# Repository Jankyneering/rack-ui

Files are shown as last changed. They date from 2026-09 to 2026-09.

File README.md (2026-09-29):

# Rack UI

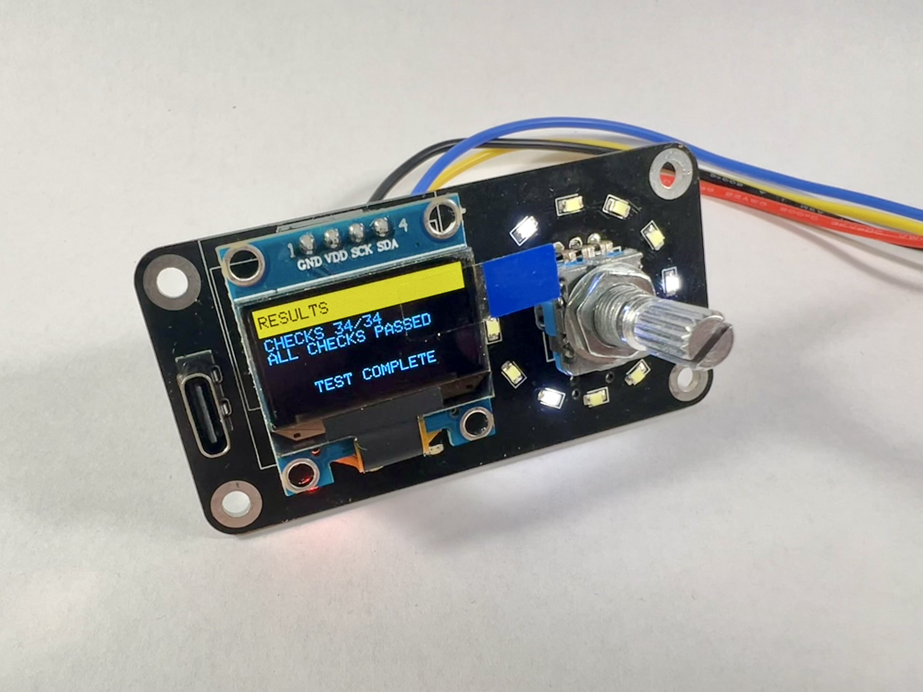
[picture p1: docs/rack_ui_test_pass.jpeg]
Rack UI - Test results

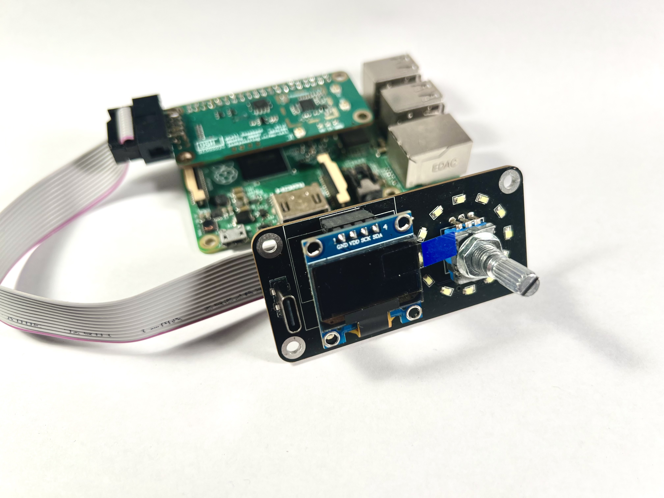
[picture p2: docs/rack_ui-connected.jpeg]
Rack UI - connected


## Contents

- [**Firmware**](firmware/src/README.md) - firmware for the Rack UI front panel controller board:
  a Puya PY32F002Ax5 (Arm Cortex-M0+) acting as an I2C peripheral, exposing a rotary encoder,
  a push button and a charlieplexed LED array to a host over a single I2C bus. Includes the
  register map, build and flashing instructions, and prebuilt release binaries.

## Flash the firmware

The Rack UI modules you can buy from the [Fred Corp. Store](https://store.fredcorp.cc) come pre-flashed with the latest firmware.

If you made your own Rack Ui board, or if you have an existing Rack Ui board that needs to be updated, you can flash the firmware using the prebuilt release binary from the [firmware release page](https://github.com/yourusername/rack-ui/releases).

### Tools

- SWD programmer (e.g. FlipperZero with DAPLink application, J-Link, etc.) compatible with the [PyOCD](https://pyocd.io/docs/debug_probes.html) toolchain.
- a [TC2030-NL](https://www.tag-connect.com/product/tc2030-idc-nl) programming probe or equivalent to connect the programmer to the Rack UI board's SWD header.

### Software dependencies

- [PyOCD](https://pyocd.io) with the [PY32F002Ax5 CMSIS pack](https://www.keil.arm.com/devices/puya-py32f002ax5/processors/) :

  ```zsh
  pip install pyocd
  pyocd pack install py32f002ax5
  ```

### Load the firmware

Use the following command to flash the firmware onto the Rack UI board. Replace `<version>` with the actual version number of the firmware you want to flash.

```zsh
pyocd load mu-cell_rack-ui_<version>.bin -t py32f002ax5
```

## Pinout

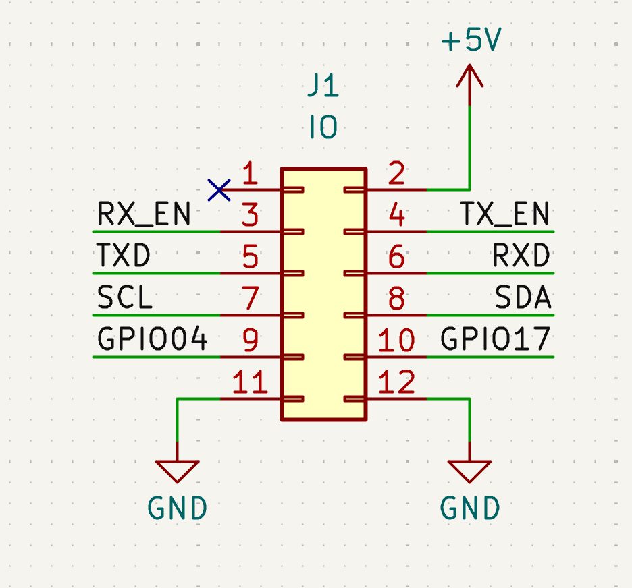
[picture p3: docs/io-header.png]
J5 expansion connector schematic


| Pin | Signal |
|---|---|
| 1 | NC |
| 2 | +5V in |
| 3 | RX_EN LED (green) |
| 4 | TX_EN LED (amber) |
| 5 | Target TXD / HT42B534-2 IC RXD |
| 6 | Target RXD / HT42B534-2 IC TXD |
| 7 | SCL |
| 8 | SDA |
| 9 | NC |
| 10 | NC |
| 11 | GND |
| 12 | GND |

---

## License & Acknowledgements

- PY32 Template from [IOsetting](https://github.com/IOsetting/py32f0-template)

Made with ❤️, lots of ☕️, and lack of 🛌  
Published under CreativeCommons BY-SA 4.0

  
This work is licensed under a [Creative Commons Attribution-ShareAlike 4.0 International License](http://creativecommons.org/licenses/by-sa/4.0/).

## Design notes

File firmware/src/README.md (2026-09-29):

# Rack UI Firmware

Firmware for the [Rack UI](../README.md) front panel controller board: a Puya **PY32F002Ax5**
(Arm Cortex-M0+) that acts as an **I2C peripheral**, exposing a rotary encoder, a push button and
a charlieplexed LED array to a host over a single I2C bus.

The firmware is built on the [py32f0-template](https://github.com/IOsetting/py32f0-template)
project using the Puya LL (Low Layer) driver library.

## What the firmware does

* **Encoder-to-I2C converter** - rotary encoder position and button presses are captured by
  interrupt and exposed through an I2C register map (see below), so a host (e.g. a Raspberry
  Pi or another MCU) can poll the panel without GPIO wiring.
* **Watchdog** - an independent watchdog (IWDG, clocked from the LSI so it keeps running
  even if the system clock fails) is enabled at boot and kicked by the main loop; if the
  firmware hangs, the MCU resets itself instead of freezing the panel. The cause of the
  last reset is exposed in register `0x02`.
* **LED driving** - 12 LEDs are driven from 4 GPIO pins by charlieplexing, with 64-step
  software PWM and optional gamma correction (curve exponent 2.2, built into a lookup table
  at boot; toggle via config bit 5). Per-LED brightness is set through registers `0x10`-`0x1B`.
  Built-in animations (loading, flashing, pulsing, breathing, ...) can drive the array
  automatically; select one through register `0x0E` and adjust its setting (speed or
  brightness) through register `0x0F`, or set it to IDLE to control the LEDs manually.
  The multiplex/PWM refresh is advanced by a TIM16 update interrupt every 24 µs, giving a
  ~54 Hz full-array refresh that is flicker-free. The main loop sleeps in `__WFI()` between
  interrupts and applies register writes between them, so I2C transactions are never blocked
  by display updates.

## Hardware / pin map

| Function | Pin | Notes |
| --- | --- | --- |
| I2C SDA | PA2 | AF12, open-drain, pull-up, 100 kHz |
| I2C SCL | PA3 | AF12, open-drain, pull-up, 100 kHz |
| Encoder A | PA5 | EXTI edge(s) per `ENCODER_TRIGGER_TOGGLE`, triggers count update (1 ms glitch guard; lines are RC-debounced by 100 nF caps) |
| Encoder B | PA4 | Input, sampled to determine rotation direction |
| Encoder switch | PA0 | EXTI both edges, debounced press counter (50 ms) |
| LED charlieplex X0 | PA6 | 12 LEDs across 4 pins |
| LED charlieplex X1 | PA7 | |
| LED charlieplex X2 | PA12 | |
| LED charlieplex X3 | PA8 | |
| Onboard LED | PB5 | Push-pull output, **active low** |

The system clock runs from the internal 8 MHz HSI. Interrupt priorities are
I2C (0) > EXTI (1) > TIM16 refresh (2), so host communication and encoder input are never
starved by the display refresh.

## I2C interface

* **Address**: `0x36` (7-bit)
* **Speed**: 100 kHz
* **Protocol**: standard register-pointer style. To read or write, first send the register
  address in a write transaction, then read or write data in the same or a following
  transaction. The register pointer auto-increments for multi-byte transfers.

### Register map

| Register | Access | Default | Description |
| --- | --- | --- | --- |
| `0x00`-`0x01` | R/W(see note) | `0x01 0x00` | **Read**: firmware version, 16-bit big-endian (BCD-friendly: v1.0 reads `0x0100`; set through `FW_VERSION_MAJOR`/`FW_VERSION_MINOR` in the Makefile). **Write**: writing any non-zero value to `0x00` issues a soft reset (the version register is not writable; a zero write is ignored). |
| `0x02` | R/O | see below | Reset cause of the most recent reset, as bit flags (see below). Latched at boot from `RCC_CSR`, then cleared there. |
| `0x03` | R/W | `0x00` | Configuration bits, see below. |
| `0x04`-`0x05` | R/W | `0x00 0x00` | Encoder rotation count, 16-bit big-endian **signed**. Incremented/decremented on rotation; cleared after the low byte is read if config bit 0 is set. |
| `0x06` | R/W | `0x00` | Encoder push button count, 8-bit unsigned. Updated on each debounced press; cleared after it is read if config bit 1 is set. |
| `0x07` | R/O | `0x00` | Encoder push button state: `0x01` while pressed (or `0x00` while pressed if config bit 4 is set). Sampled live when this register is transmitted. |
| `0x08`-`0x0D` | R/O | `0x00` | Reserved for future encoder settings. Reads return `0x00`; writes are ignored. |
| `0x0E` | R/W | `0x80` | Active animation, see [below](#animation-register-0x0e). |
| `0x0F` | R/W | `0x00` | Setting of the animation selected through `0x0E`, see [below](#animation-settings-register-0x0f). Writing a new animation id to `0x0E` reloads this register with that animation's default. |
| `0x10`-`0x1B` | R/W | `0x00` | LED brightness, one register per LED (LED 0 = `0x10` ... LED 11 = `0x1B`). `0x00` = off, `0x40` = full on; values above `0x40` clamp to full on. In IDLE mode (`0x0E` = `0x00`) these registers drive the LEDs directly; while an animation is running, the animation overwrites them. |
| `0x1C`-`0x1F` | R/O | `0x00` | Reserved. Reads return `0x00`; writes are ignored. |
| `0x20`-`0xFF` | R/W | `0x00` | General-purpose I2C RAM. Not used by the firmware; usable as 224 bytes of host scratch space. |

### Config register (`0x03`)

| Bit | Default | Description |
| --- | --- | --- |
| 0 | `0` | `1` = clear the rotation count (`0x04`-`0x05`) to zero after the low byte (`0x05`) is read. `0` (default) = keep the count. |
| 1 | `0` | `1` = clear the push count (`0x06`) to zero after it is read. `0` (default) = keep the count. |
| 2 | `0` | `1` = flip encoder increment direction. |
| 3 | `0` | `1` = decrement push count on press (saturates at 0, e.g. for "count down remaining presses" logic), `0` = increment (wraps past 255). |
| 4 | `0` | `1` = invert the reported push button state: unpressed reads `1`, pressed reads `0`. |
| 5 | `0` | `0` = gamma-correct LED brightness (default), `1` = linear brightness. |
| 6-7 | `0` | Reserved, always read 0. |

Notes:

* Writes to read-only registers are ignored (the register pointer still advances, so
  multi-byte writes can skip over them).
* A soft reset completes the current I2C transaction first, then resets the MCU; the bus
  release means the master sees a normal STOP rather than a stuck line. After reset, all
  registers return to their power-on defaults.
* The rotation counter is big-endian; read `0x04` then `0x05` in one transaction for a
  coherent value.
* Register defaults are reinitialised only at power-on/reset; the general-purpose RAM is not
  preserved across resets.

### Reset cause register (`0x02`)

Reports why the MCU last reset, latched from `RCC_CSR` at boot (then cleared
there, so the register shows the most recent reset rather than everything
accumulated since power-on). Multiple bits can be set when several causes
contributed.

| Bit | Name | Reset type |
| --- | --- | --- |
| 0 | `POR` | Power-on / brown-out (BOR/POR/PDR) reset |
| 1 | `PIN` | NRST pin reset |
| 2 | `SOFT` | Software reset (a non-zero write to register `0x00`) |
| 3 | `IWDG` | Independent watchdog timeout |
| 4 | `WWDG` | Window watchdog reset |
| 5 | `OBL` | Option byte loader reset |

A watchdog recovery therefore reads back with bit 3 (and typically bit 1) set.

### Watchdog

The independent watchdog (IWDG) is enabled once at boot with a timeout of
`IWDG_TIMEOUT_MS` (default 500 ms) and kicked by the main loop, which wakes at
least once per animation tick. It runs from the ~32 kHz LSI, independent of the
system clock, so it also recovers from a loss of the HSI. Once enabled it can
only be stopped by a reset; the soft-reset command (register `0x00`) restarts
it cleanly. While the core is halted under a debugger the watchdog is frozen
(`DBGMCU` IWDG stop), so breakpoints do not trip a reset.

### Animation register (`0x0E`)

Selects the LED animation. New animations are added by extending the table in
`User/animations.c` (see `User/animations.h` for the ID enum); unknown values fall
back to `IDLE`.

| Value | Name | Description |
| --- | --- | --- |
| `0x00` | `IDLE` | Custom control: the LEDs are driven manually via registers `0x10`-`0x1B`. |
| `0x01` | `LOADING` | Rotating loading pattern, one LED at a time reaching full brightness. |
| `0x02` | `FLASHING` | All LEDs flash on and off. |
| `0x03` | `PULSING` | All LEDs smoothly ramp up and down in brightness. |
| `0x04` | `BREATHING` | All LEDs smoothly fade in, hold, fade out and pause. |
| `0x80` | `FOLLOWING` | Every 4th LED is lit and the pattern follows the encoder rotation (configurable with the `ANIMATION_FOLLOWING_LED_STEPS` constant). |
| `0x81` | `POINT` | One LED follows the encoder rotation. |
| `0x82` | `GAUGE` | The LEDs form a bar graph, with the number of lit LEDs proportional to the encoder rotation count. The count is scaled against the maximum value set through `0x0F` (default 100) and capped between 0 and that maximum. The LEDs outside the gauge arc are held at a low brightness when `ANIMATION_GAUGE_DIM_UNUSED_LEDS` is defined (default), otherwise they keep their previous state. |
| `0x83` | `GAUGE_CENTER` | Centered version of the gauge: the middle LED of the arc is always lit, and the arc fills outward from it in one direction for positive encoder counts and the other for negative ones. The count is scaled against the positive/negative limit set through `0x0F` (default 50) and clamped symmetrically to `-limit..+limit`; the clamped value is written back to the count registers. The LEDs outside the gauge arc are dimmed like `GAUGE`. |
| `0xFE` | `ALL_ON` | All LEDs on at the brightness set through `0x0F`. Default to `CHARLIE_PWM_STEPS - 1`. |
| `0xFF` | `ALL_OFF` | All LEDs off. |

### Animation settings register (`0x0F`)

Holds the setting of the animation selected through register `0x0E` (timing
for LOADING/FLASHING/PULSING, brightness for ALL_ON, the off-state brightness
of the non-lit LEDs for FOLLOWING/POINT, the maximum value for GAUGE and the
positive/negative limit for GAUGE_CENTER).
Writing a new animation id to `0x0E` loads that animation's default into
`0x0F`; a subsequent write to `0x0F` adjusts the setting while the animation
keeps running. A value of `0` is ignored and keeps the current setting.

| Animation | Scale | Default | Meaning |
| --- | --- | --- | --- |
| `IDLE` | - | `0x00` | No setting. |
| `LOADING` | x10 ms | `10` (100 ms) | Time between LED steps of the loading pattern. |
| `FLASHING` | x10 ms | `25` (250 ms) | Time between LED state toggles. |
| `PULSING` | x1 ms | `10` (10 ms) | Time between LED brightness changes. |
| `BREATHING` | - | `0x00` | Timing fixed by the `ANIMATION_BREATHING_*` constants; no runtime setting. |
| `FOLLOWING` | x brightness | `0` (off) | Brightness of the LEDs that are not lit. |
| `POINT` | x brightness | `0` (off) | Brightness of the LEDs that are not lit. |
| `GAUGE` | x gauge max | `100` | Maximum value of the gauge range (e.g. `10` for 0-10, `250` for 0-250); the encoder count is capped between 0 and this value. |
| `GAUGE_CENTER` | x gauge limit | `50` | Positive/negative limit of the centered gauge (e.g. `10` for -10 to +10, `250` for -250 to +250); the encoder count is clamped symmetrically to `-limit..+limit` and each half of the arc covers `0..limit`. |
| `ALL_ON` | x brightness | `63` (full on) | Brightness of all LEDs. |
| `ALL_OFF` | - | `0x00` | No setting. |

Animations write their brightness values to the LED registers (`0x10`-`0x1B`) and
mark them dirty, so the main loop applies them exactly like host writes. The
animation engine ticks every 11 ms from the main loop.

### Examples (Linux `i2c-tools`)

```bash
# Read the firmware version (expects 0x00 0x01)
i2ctransfer -y 1 w1@0x36 0x00 r2

# Read the 16-bit encoder rotation count
i2ctransfer -y 1 w1@0x36 0x04 r2

# Read the button state and push count
i2cget -y 1 0x36 0x07
i2cget -y 1 0x36 0x06
# Read the reset cause of the last boot (bit flags, see the register table)
i2cget -y 1 0x36 0x02

# Enable reset-on-read for the rotation count and push count
i2cset -y 1 0x36 0x03 0x03

# Soft-reset the device (registers return to power-on defaults)
i2cset -y 1 0x36 0x00 0x01

# Set LED 0 to quarter brightness and LED 11 to full, gamma-corrected
i2cset -y 1 0x36 0x10 0x10
i2cset -y 1 0x36 0x1B 0x40

# Set all 12 LED brightness registers in one transaction
i2ctransfer -y 1 w13@0x36 0x10 0x40 0x40 0x40 0x40 0x40 0x40 0x40 0x40 0x40 0x40 0x40 0x40

# Flip encoder direction and switch LEDs to linear brightness
i2cset -y 1 0x36 0x03 0x24

# Switch to manual LED control (IDLE), then set LED 0 to quarter brightness
i2cset -y 1 0x36 0x0E 0x00
i2cset -y 1 0x36 0x10 0x10

# Switch to the pulsing animation; its default 10 ms pulse delay is loaded
# into register 0x0F
i2cset -y 1 0x36 0x0E 0x03

# Speed the pulsing animation up to a 5 ms delay
i2cset -y 1 0x36 0x0F 0x05

# Switch to the loading animation (100 ms default step time), then slow the
# rotation to 500 ms per step
i2cset -y 1 0x36 0x0E 0x01
i2cset -y 1 0x36 0x0F 0x32

# Turn all LEDs on at the default full brightness, then dim them to half
i2cset -y 1 0x36 0x0E 0xFE
i2cset -y 1 0x36 0x0F 0x20

# Switch to the gauge animation (maximum 100 is loaded into 0x0F), then
# change the range to 0-10 so each encoder detent fills a tenth of the arc
i2cset -y 1 0x36 0x0E 0x82
i2cset -y 1 0x36 0x0F 0x0A
# Switch to the centered gauge animation (limit 50 is loaded into 0x0F, so the
# count is clamped to -50..+50), then change the limit to 10 for -10 to +10
i2cset -y 1 0x36 0x0E 0x83
i2cset -y 1 0x36 0x0F 0x0A

# Turn all LEDs off
i2cset -y 1 0x36 0x0E 0xFF

# Use register 0x20 as scratch RAM
i2cset -y 1 0x36 0x20 0xA5
i2cget -y 1 0x36 0x20
```

## Building

### 1. Install the GNU Arm Embedded toolchain

Download the toolchain from
[Arm GNU Toolchain Downloads](https://developer.arm.com/downloads/-/arm-gnu-toolchain-downloads)
for your architecture and extract it, or install a distribution package:

```bash
# Debian/Ubuntu
sudo apt-get install gcc-arm-none-eabi libnewlib-arm-none-eabi
# -> toolchain in /usr/bin, set ARM_TOOLCHAIN=/usr/bin when building
```

### 2. Build

From the `firmware/src` directory:

```bash
make ARM_TOOLCHAIN=/usr/bin        # or point ARM_TOOLCHAIN at your toolchain's bin/ directory
```

Useful variants:

```bash
make clean                        # remove build products
V=1 make                          # verbose output (prints full command lines)
make echo-version                 # print the firmware version (MAJOR.MINOR)
```

The firmware version is defined in the Makefile through `FW_VERSION_MAJOR` /
`FW_VERSION_MINOR` (default 1.0); it is baked into registers `0x00`-`0x01` and
names the build products. Override it for a local build with:

```bash
make ARM_TOOLCHAIN=/usr/bin FW_VERSION_MAJOR=2 FW_VERSION_MINOR=3
```

#### Build flags and tunable constants

Optional `#define` flags live in the header that owns them: toggle them there
(or pass them on the compiler command line through `LIB_FLAGS` in the
Makefile) and rebuild.

Encoder flags in `User/main.h`:

* `ENCODER_TRIGGER_TOGGLE` (undefined by default) - define it to count both EncA
  edges (one tick per detent on encoders that produce one edge per detent); leave it
  commented out to count the falling edge only
* `ENCODER_DIRECTION_FLIP` (undefined by default) - define it to make clockwise
  rotation decrement the count instead of incrementing, for encoder models with
  reversed phase wiring; composes with the runtime `CFG_ENC_DIR_FLIP` config bit
* `ENCODER_AB_SWAP` (defined) - swap the phase inputs
  (EncA moves to PA4, EncB to PA5) for encoder models whose trigger output sits on
  the other phase or whose A/B pins are wired the other way round; note that
  swapping the phases also inverts the decoded direction, so combine it with
  `ENCODER_DIRECTION_FLIP` to keep the increment direction

Animation flags in `User/animations.h`:

* `ANIMATION_GAUGE_DIM_UNUSED_LEDS` (defined) - while the GAUGE or
  GAUGE_CENTER animation is active, hold the three LEDs outside the gauge arc
  at a low fixed brightness (`ANIMATION_GAUGE_UNUSED_BRIGHTNESS`) instead of
  leaving them at whatever state the previous animation or host writes left
  them in; comment it out to keep the previous state

Tunable constants (same headers, adjust and rebuild; defaults in parentheses):

* `ANIMATION_DEFAULT` (`ANIMATION_FOLLOWING`) - animation selected at power-on
  and after a soft reset
* `ANIMATION_GAUGE_SETTINGS_DEFAULT` (`100`) - gauge maximum loaded into `0x0F`
  when GAUGE is selected through `0x0E`
* `ANIMATION_GAUGE_CENTER_SETTINGS_DEFAULT` (`50`) - positive/negative gauge
  limit loaded into `0x0F` when GAUGE_CENTER is selected through `0x0E`
* `ANIMATION_GAUGE_START_LED` / `ANIMATION_GAUGE_LED_COUNT` (`8` / `9`) - first
  LED and number of LEDs forming the gauge arc; the remaining LEDs are the
  "unused" ones covered by `ANIMATION_GAUGE_DIM_UNUSED_LEDS`
* `ANIMATION_GAUGE_UNUSED_BRIGHTNESS` (`8`) - brightness of the non-gauge LEDs
  while the dim flag is in effect (`0`-`CHARLIE_PWM_STEPS - 1`)
* `ANIMATION_FOLLOWING_LED_STEPS` (`4`) - every Nth LED is lit in FOLLOWING
* `ANIMATION_BREATHING_IN_MS` / `ANIMATION_BREATHING_HOLD_MS` /
  `ANIMATION_BREATHING_OUT_MS` / `ANIMATION_BREATHING_PAUSE_MS`
  (`1500` / `750` / `2500` / `2000`) - phase durations of the breathing animation
* `ANIMATION_*_SETTINGS_DEFAULT` - defaults loaded into `0x0F` when the
  matching animation is selected (step time for LOADING/FLASHING/PULSING,
  brightness for ALL_ON, off-state brightness for FOLLOWING/POINT, gauge maximum
  for GAUGE, positive/negative limit for GAUGE_CENTER)
* `ANIMATION_LOADING_SETTINGS_MS` / `ANIMATION_FLASHING_SETTINGS_MS` (`10`) and
  `ANIMATION_PULSING_SETTINGS_MS` (`1`) - milliseconds per `0x0F` register step
* `ANIMATION_TICK_MS` (`11`) - animation engine tick, driven from the main loop
* `CHARLIE_GAMMA` (`2.2`, in `User/charlieplex.h`) - gamma exponent of the LED
  brightness curve (2.0 = simple square law, 2.2 ≈ perceptual/sRGB-style curve)
* `I2C_SLAVE_ADDR` (`0x36`, in `User/main.h`) - I2C bus address of the device
* `IWDG_TIMEOUT_MS` (`500`, in `User/main.h`) - independent watchdog timeout in
  milliseconds; the main loop must wake at least once per period or the MCU resets

Toolchain-level defines, set through the Makefile rather than a header:

* `FW_VERSION` - firmware version baked into registers `0x00`-`0x01`, derived
  from `FW_VERSION_MAJOR`/`FW_VERSION_MINOR`
* `USE_FULL_ASSERT` (undefined by default) - enable the LL drivers' parameter
  checking: `assert_param` reports the source file and line when a driver is
  called with an invalid parameter; costs some code size

Output files land in `firmware/src/Build/`, named after the app and version
(`mu-cell_rack-ui_vMAJOR.MINOR`):

| File | Description |
| --- | --- |
| `mu-cell_rack-ui_vX.Y.bin` | Raw binary image, for flashing |
| `mu-cell_rack-ui_vX.Y.hex` | Intel HEX image |
| `mu-cell_rack-ui_vX.Y.elf` | ELF with debug symbols |
| `mu-cell_rack-ui_vX.Y.lst` | Disassembly listing |

### 3. Flash

The Makefile supports flashing via **PyOCD** (DAPLink or J-Link probes) or **J-Link**,
selected with `FLASH_PROGRM`:

```bash
make ARM_TOOLCHAIN=/usr/bin flash          # uses pyocd (default)
make ARM_TOOLCHAIN=/usr/bin FLASH_PROGRM=jlink flash
```

Refer to the [py32f0-template wiki](https://github.com/IOsetting/py32f0-template/wiki)
for detailed tooling setup (PyOCD, J-Link, VS Code debugging).

## CI and releases

The [firmware workflow](../.github/workflows/firmware.yml) builds the firmware on every push
to `main`, on pull requests and on `vX.Y` tags, uploading the build outputs as an artifact.
On each push to `main`, a **nightly** rolling release is published containing the latest
`.bin` (plus `.hex` and `.elf`), named `mu-cell_rack-ui_nightly-<commit>` with the commit it
was built from. Pushing a `vX.Y` tag instead publishes a versioned release: the firmware is
built with the tagged version and the assets are named `mu-cell_rack-ui_vX.Y.bin/.elf/.hex`.
You can grab prebuilt binaries from the repository's
[releases page](https://github.com/Jankyneering/rack-ui/releases) without installing a
toolchain.

## License & Acknowledgements

* PY32 Template from [IOsetting](https://github.com/IOsetting/py32f0-template)

Published under CreativeCommons BY-SA 4.0



This work is licensed under a [Creative Commons Attribution-ShareAlike 4.0 International License](http://creativecommons.org/licenses/by-sa/4.0/).

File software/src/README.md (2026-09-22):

# Rack UI Firmware

Firmware for the [Rack UI](../README.md) front panel controller board: a Puya **PY32F002Ax5**
(Arm Cortex-M0+) that acts as an **I2C peripheral**, exposing a rotary encoder, a push button and
a charlieplexed LED array to a host over a single I2C bus.

The firmware is built on the [py32f0-template](https://github.com/IOsetting/py32f0-template)
project using the Puya LL (Low Layer) driver library.

## What the firmware does

* **Encoder-to-I2C converter** - rotary encoder position and button presses are captured by
  interrupt and exposed through an I2C register map (see below), so a host (e.g. a Raspberry
  Pi or another MCU) can poll the panel without GPIO wiring.
* **LED driving** - 12 LEDs are driven from 4 GPIO pins by charlieplexing, with 64-step
  software PWM and optional gamma correction (curve exponent 2.2, built into a lookup table
  at boot; toggle via config bit 5). Per-LED brightness is set through registers `0x10`-`0x1B`.
  Built-in animations (loading, flashing, pulsing, breathing, ...) can drive the array
  automatically; select one through register `0x0E` and adjust its setting (speed or
  brightness) through register `0x0F`, or set it to IDLE to control the LEDs manually.
  The multiplex/PWM refresh is advanced by a TIM16 update interrupt every 24 µs, giving a
  ~54 Hz full-array refresh that is flicker-free. The main loop sleeps in `__WFI()` between
  interrupts and applies register writes between them, so I2C transactions are never blocked
  by display updates.

## Hardware / pin map

| Function | Pin | Notes |
| --- | --- | --- |
| I2C SDA | PA2 | AF12, open-drain, pull-up, 100 kHz |
| I2C SCL | PA3 | AF12, open-drain, pull-up, 100 kHz |
| Encoder A | PA5 | EXTI edge(s) per `ENCODER_TRIGGER_TOGGLE`, triggers count update (1 ms glitch guard; lines are RC-debounced by 100 nF caps) |
| Encoder B | PA4 | Input, sampled to determine rotation direction |
| Encoder switch | PA0 | EXTI both edges, debounced press counter (50 ms) |
| LED charlieplex X0 | PA6 | 12 LEDs across 4 pins |
| LED charlieplex X1 | PA7 | |
| LED charlieplex X2 | PA12 | |
| LED charlieplex X3 | PA8 | |
| Onboard LED | PB5 | Push-pull output, **active low** |

The system clock runs from the internal 8 MHz HSI. Interrupt priorities are
I2C (0) > EXTI (1) > TIM16 refresh (2), so host communication and encoder input are never
starved by the display refresh.

## I2C interface

* **Address**: `0x36` (7-bit)
* **Speed**: 100 kHz
* **Protocol**: standard register-pointer style. To read or write, first send the register
  address in a write transaction, then read or write data in the same or a following
  transaction. The register pointer auto-increments for multi-byte transfers.

### Register map

| Register | Access | Default | Description |
| --- | --- | --- | --- |
| `0x00`-`0x01` | R/W(see note) | `0x00 0x01` | **Read**: firmware version, 16-bit big-endian (BCD-friendly: v0.1 reads `0x0001`). **Write**: writing any non-zero value to `0x00` issues a soft reset (the version register is not writable; a zero write is ignored). |
| `0x02` | R/W | `0x00` | Configuration bits, see below. |
| `0x03`-`0x04` | R/W | `0x00 0x00` | Encoder rotation count, 16-bit big-endian **signed**. Incremented/decremented on rotation; cleared after the low byte is read if config bit 0 is set. |
| `0x05` | R/W | `0x00` | Encoder push button count, 8-bit unsigned. Updated on each debounced press; cleared after it is read if config bit 1 is set. |
| `0x06` | R/O | `0x00` | Encoder push button state: `0x01` while pressed (or `0x00` while pressed if config bit 4 is set). Sampled live when this register is transmitted. |
| `0x07`-`0x0D` | R/O | `0x00` | Reserved for future encoder settings. Reads return `0x00`; writes are ignored. |
| `0x0E` | R/W | `0xFE` | Active animation, see [below](#animation-register-0x0e). |
| `0x0F` | R/W | `0x3F` | Setting of the animation selected through `0x0E`, see [below](#animation-settings-register-0x0f). Writing a new animation id to `0x0E` reloads this register with that animation's default. |
| `0x10`-`0x1B` | R/W | `0x00` | LED brightness, one register per LED (LED 0 = `0x10` ... LED 11 = `0x1B`). `0x00` = off, `0x40` = full on; values above `0x40` clamp to full on. In IDLE mode (`0x0E` = `0x00`) these registers drive the LEDs directly; while an animation is running, the animation overwrites them. |
| `0x1C`-`0x1F` | R/O | `0x00` | Reserved. Reads return `0x00`; writes are ignored. |
| `0x20`-`0xFF` | R/W | `0x00` | General-purpose I2C RAM. Not used by the firmware; usable as 224 bytes of host scratch space. |

### Config register (`0x02`)

| Bit | Default | Description |
| --- | --- | --- |
| 0 | `0` | `1` = clear the rotation count (`0x03`-`0x04`) to zero after the low byte (`0x04`) is read. `0` (default) = keep the count. |
| 1 | `0` | `1` = clear the push count (`0x05`) to zero after it is read. `0` (default) = keep the count. |
| 2 | `0` | `1` = flip encoder increment direction. |
| 3 | `0` | `1` = decrement push count on press (saturates at 0, e.g. for "count down remaining presses" logic), `0` = increment (wraps past 255). |
| 4 | `0` | `1` = invert the reported push button state: unpressed reads `1`, pressed reads `0`. |
| 5 | `0` | `0` = gamma-correct LED brightness (default), `1` = linear brightness. |
| 6-7 | `0` | Reserved, always read 0. |

Notes:

* Writes to read-only registers are ignored (the register pointer still advances, so
  multi-byte writes can skip over them).
* A soft reset completes the current I2C transaction first, then resets the MCU; the bus
  release means the master sees a normal STOP rather than a stuck line. After reset, all
  registers return to their power-on defaults.
* The rotation counter is big-endian; read `0x03` then `0x04` in one transaction for a
  coherent value.
* Register defaults are reinitialised only at power-on/reset; the general-purpose RAM is not
  preserved across resets.

### Animation register (`0x0E`)

Selects the LED animation. New animations are added by extending the table in
`User/animations.c` (see `User/animations.h` for the ID enum); unknown values fall
back to `IDLE`.

| Value | Name | Description |
| --- | --- | --- |
| `0x00` | `IDLE` | Custom control: the LEDs are driven manually via registers `0x10`-`0x1B`. |
| `0x01` | `LOADING` | Rotating loading pattern, one LED at a time reaching full brightness. |
| `0x02` | `FLASHING` | All LEDs flash on and off. |
| `0x03` | `PULSING` | All LEDs smoothly ramp up and down in brightness. |
| `0x04` | `BREATHING` | All LEDs smoothly fade in, hold, fade out and pause. |
| `0x80` | `FOLLOWING` | Every 4th LED is lit and the pattern follows the encoder rotation (configurable with the `ANIMATION_FOLLOWING_LED_STEPS` constant). |
| `0x81` | `POINT` | One LED follows the encoder rotation. |
| `0x82` | `GAUGE` | The LEDs form a bar graph, with the number of lit LEDs proportional to the encoder rotation count. The encoder count is capped between 0 and 100. |
| `0xFE` | `ALL_ON` | All LEDs on at the brightness set through `0x0F`. Default to `CHARLIE_PWM_STEPS - 1`. |
| `0xFF` | `ALL_OFF` | All LEDs off. |

### Animation settings register (`0x0F`)

Holds the setting of the animation selected through register `0x0E` (timing
for LOADING/FLASHING/PULSING, brightness for ALL_ON and the off-state
brightness of the non-lit LEDs for FOLLOWING/POINT). Writing a new animation id
to `0x0E` loads that animation's default into `0x0F`; a subsequent write to
`0x0F` adjusts the setting while the animation keeps running. A value of `0` is
ignored and keeps the current setting.

| Animation | Scale | Default | Meaning |
| --- | --- | --- | --- |
| `IDLE` | - | `0x00` | No setting. |
| `LOADING` | x10 ms | `10` (100 ms) | Time between LED steps of the loading pattern. |
| `FLASHING` | x10 ms | `25` (250 ms) | Time between LED state toggles. |
| `PULSING` | x1 ms | `10` (10 ms) | Time between LED brightness changes. |
| `BREATHING` | - | `0x00` | Timing fixed by the `ANIMATION_BREATHING_*` constants; no runtime setting. |
| `FOLLOWING` | x brightness | `0` (off) | Brightness of the LEDs that are not lit. |
| `POINT` | x brightness | `0` (off) | Brightness of the LEDs that are not lit. |
| `GAUGE` | - | `0x00` | No runtime setting. |
| `ALL_ON` | x brightness | `63` (full on) | Brightness of all LEDs. |
| `ALL_OFF` | - | `0x00` | No setting. |

Animations write their brightness values to the LED registers (`0x10`-`0x1B`) and
mark them dirty, so the main loop applies them exactly like host writes. The
animation engine ticks every 11 ms from the main loop.

### Examples (Linux `i2c-tools`)

```bash
# Read the firmware version (expects 0x00 0x01)
i2ctransfer -y 1 w1@0x36 0x00 r2

# Read the 16-bit encoder rotation count
i2ctransfer -y 1 w1@0x36 0x03 r2

# Read the button state and push count
i2cget -y 1 0x36 0x06
i2cget -y 1 0x36 0x05

# Enable reset-on-read for the rotation count and push count
i2cset -y 1 0x36 0x02 0x03

# Soft-reset the device (registers return to power-on defaults)
i2cset -y 1 0x36 0x00 0x01

# Set LED 0 to quarter brightness and LED 11 to full, gamma-corrected
i2cset -y 1 0x36 0x10 0x10
i2cset -y 1 0x36 0x1B 0x40

# Set all 12 LED brightness registers in one transaction
i2ctransfer -y 1 w13@0x36 0x10 0x40 0x40 0x40 0x40 0x40 0x40 0x40 0x40 0x40 0x40 0x40 0x40

# Flip encoder direction and switch LEDs to linear brightness
i2cset -y 1 0x36 0x02 0x24

# Switch to manual LED control (IDLE), then set LED 0 to quarter brightness
i2cset -y 1 0x36 0x0E 0x00
i2cset -y 1 0x36 0x10 0x10

# Switch to the pulsing animation; its default 10 ms pulse delay is loaded
# into register 0x0F
i2cset -y 1 0x36 0x0E 0x03

# Speed the pulsing animation up to a 5 ms delay
i2cset -y 1 0x36 0x0F 0x05

# Switch to the loading animation (100 ms default step time), then slow the
# rotation to 500 ms per step
i2cset -y 1 0x36 0x0E 0x01
i2cset -y 1 0x36 0x0F 0x32

# Turn all LEDs on at the default full brightness, then dim them to half
i2cset -y 1 0x36 0x0E 0xFE
i2cset -y 1 0x36 0x0F 0x20

# Turn all LEDs off
i2cset -y 1 0x36 0x0E 0xFF

# Use register 0x20 as scratch RAM
i2cset -y 1 0x36 0x20 0xA5
i2cget -y 1 0x36 0x20
```

## Building

### 1. Install the GNU Arm Embedded toolchain

Download the toolchain from
[Arm GNU Toolchain Downloads](https://developer.arm.com/downloads/-/arm-gnu-toolchain-downloads)
for your architecture and extract it, or install a distribution package:

```bash
# Debian/Ubuntu
sudo apt-get install gcc-arm-none-eabi libnewlib-arm-none-eabi
# -> toolchain in /usr/bin, set ARM_TOOLCHAIN=/usr/bin when building
```

### 2. Build

From the `software/src` directory:

```bash
make ARM_TOOLCHAIN=/usr/bin        # or point ARM_TOOLCHAIN at your toolchain's bin/ directory
```

Useful variants:

```bash
make clean                        # remove build products
V=1 make                          # verbose output (prints full command lines)
```

Encoder build flags in `User/main.h`:

- `ENCODER_TRIGGER_TOGGLE` (undefined by default) - define it to count both EncA
  edges (one tick per detent on encoders that produce one edge per detent); leave it
  commented out to count the falling edge only
- `ENCODER_DIRECTION_FLIP` (undefined by default) - define it to make clockwise
  rotation decrement the count instead of incrementing, for encoder models with
  reversed phase wiring; composes with the runtime `CFG_ENC_DIR_FLIP` config bit
- `ENCODER_AB_SWAP` (defined) - swap the phase inputs
  (EncA moves to PA4, EncB to PA5) for encoder models whose trigger output sits on
  the other phase or whose A/B pins are wired the other way round; note that
  swapping the phases also inverts the decoded direction, so combine it with
  `ENCODER_DIRECTION_FLIP` to keep the increment direction

Output files land in `software/src/Build/`:

| File | Description |
| --- | --- |
| `app.bin` | Raw binary image, for flashing |
| `app.hex` | Intel HEX image |
| `app.elf` | ELF with debug symbols |
| `app.lst` | Disassembly listing |

### 3. Flash

The Makefile supports flashing via **PyOCD** (DAPLink or J-Link probes) or **J-Link**,
selected with `FLASH_PROGRM`:

```bash
make ARM_TOOLCHAIN=/usr/bin flash          # uses pyocd (default)
make ARM_TOOLCHAIN=/usr/bin FLASH_PROGRM=jlink flash
```

Refer to the [py32f0-template wiki](https://github.com/IOsetting/py32f0-template/wiki)
for detailed tooling setup (PyOCD, J-Link, VS Code debugging).

## CI and nightly builds

The [firmware workflow](../.github/workflows/firmware.yml) builds the firmware on every push
to `main` and on pull requests, uploading the build outputs as an artifact. On each push to
`main`, a **nightly** rolling release is published containing the latest `app.bin` (plus
`.hex` and `.elf`), named with the commit it was built from. You can grab prebuilt binaries
from the repository's [releases page](https://github.com/Jankyneering/rack-ui/releases)
without installing a toolchain.

## License & Acknowledgements

* PY32 Template from [IOsetting](https://github.com/IOsetting/py32f0-template)

Published under CreativeCommons BY-SA 4.0



This work is licensed under a [Creative Commons Attribution-ShareAlike 4.0 International License](http://creativecommons.org/licenses/by-sa/4.0/).

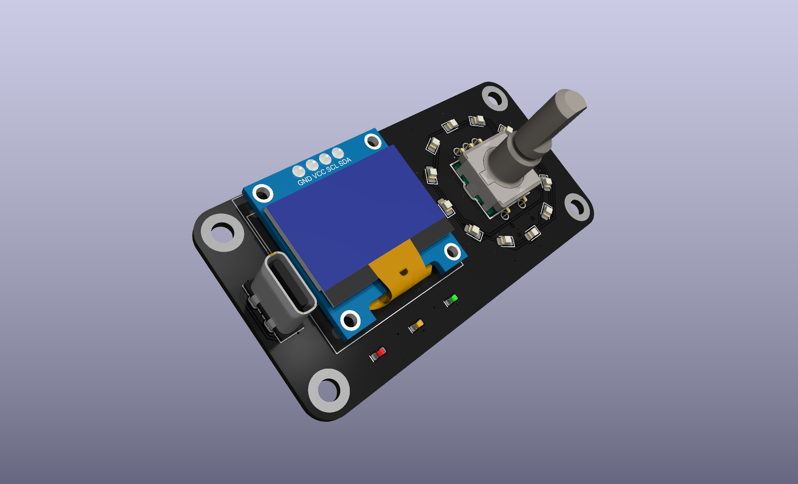
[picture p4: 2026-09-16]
docs/rack-ui-pcb_3-4_Up.png

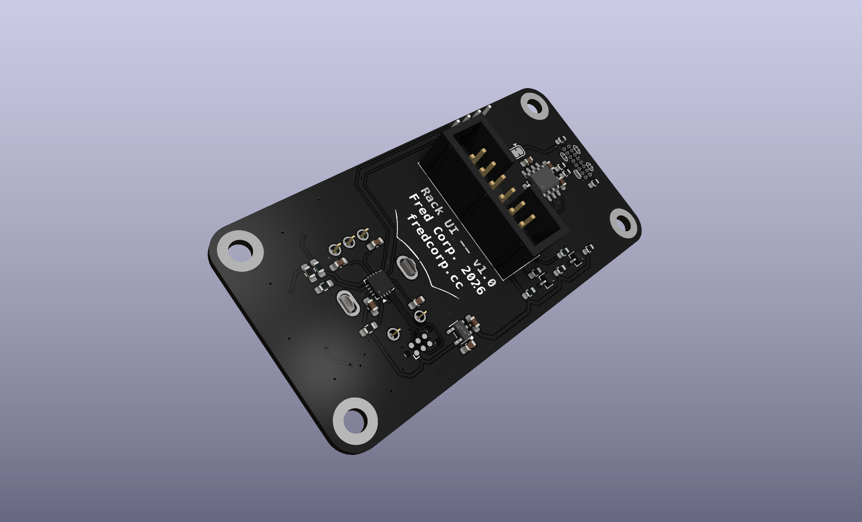
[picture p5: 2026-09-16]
docs/rack-ui-pcb_3-4_Down.png

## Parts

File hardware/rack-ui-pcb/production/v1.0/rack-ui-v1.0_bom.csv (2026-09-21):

Designator | Footprint | Quantity | Value | LCSC Part #
C1, C2, C4 | 0603 | 3 | 1u | C59302
C10, C3, C5, C8, C9 | 0603 | 5 | 100n | C235731
C6, C7 | 0603 | 2 | 47p | C1671
J1 | IDC-Header_2x06_P2.54mm_Vertical | 1 | IO | C109410
LED1 | 0603 | 1 | Red | C52675987
LED10, LED11, LED12, LED13, LED14, LED15, LED4, LED5, LED6, LED7, LED8, LED9 | 0805 | 12 | SZYY0805W | C434434
LED2 | 0603 | 1 | Amber | C165983
LED3 | 0603 | 1 | Green | C51933293
Q1, Q2 | SOT-323_SC-70 | 2 | BC817-40W | C383187
R1, R2 | 0603 | 2 | 5.1k | C2907114
R10, R11, R12, R13 | 0603 | 4 | 27 | C2907136
R3, R4 | 0603 | 2 | 33 | C2907154
R5, R6, R7, R8, R9 | 0603 | 5 | 1K | C2907002
SW1 | SW-TH_EC11E18244A5 | 1 | EC11E18244A5 | C255515
U1 | WQFN-16-1EP_3x3mm_P0.5mm_EP1.75x1.75mm | 1 | PY32F002AW15U | C5291740
U2 | SOP-8_L4.9-W3.9-P1.27-LS6.0-BL | 1 | HT42B534-2 | C493294
U3 | SOT-23-5_L3.0-W1.7-P0.95-LS2.8-BL | 1 | ME6211C33M5G-N | C82942
USB1 | USB-TH_JS16H-TYPE-C449-H105-1 | 1 | JS16H-TYPE-C449-H105 | C49118459

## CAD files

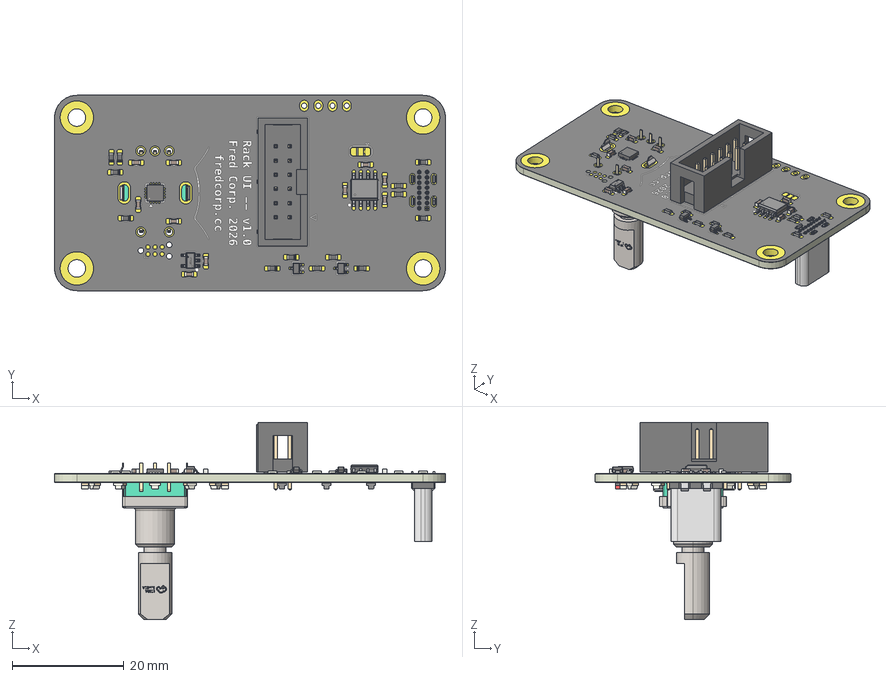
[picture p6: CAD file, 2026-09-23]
hardware/rack-ui-pcb/rack-ui-pcb.step
70.0 x 35.0 x 35.3 mm
R_0603_1608Metric x 13
C_0603_1608Metric x 10
WQFN_16_1EP_3x3mm_P05mm_EP16x16mm
SOT-323_SC-70 x 2
SOT-23-5_L2.9-W1.6-H1.1-LS2.8-P0.95
SOP-8_L4.9-W3.9-P1.27-LS6.0-BL-1
IDC_Header_2x06_P254mm_Vertical
LED_0805_2012Metric x 12
LED_0603_1608Metric_Green
LED_0603_1608Metric_Red
X-axis x 9
XY-plane x 9
Sketch
Sketch001
Sketch002
Sketch003
AdditiveLoft
Sketch004
MultiTransform
Structure
Sketch005
Sketch006
MultiTransform001
Sketch007
Sketch008
Binder
Sketch009
Pins
Binder001
Sketch010
MultiTransform002
SW-TH_EC11E18244A5-L11.7-W12.0-H24.5-P2.5-LS14.5
LED_0603_1608Metric_Blue
rack-ui-pcb-unsaved-export-Aar9UT_copper
rack-ui-pcb-unsaved-export-Aar9UT_silkscreen x 2
rack-ui-pcb-unsaved-export-Aar9UT_soldermask x 2
rack-ui-pcb-unsaved-export-Aar9UT_PCB

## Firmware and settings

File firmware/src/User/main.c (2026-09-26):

#include "main.h"
#include "animations.h"
#include <stddef.h>

/* I2C Configuration */
#define SLAVE_ADDRESS (I2C_SLAVE_ADDR << 1)
#define I2C_SPEEDCLOCK 100000

/* Private variables */
volatile uint8_t device_memory[REG_COUNT];
volatile uint8_t current_reg_ptr   = 0;
__IO I2C_Slave_State_t slave_state = I2C_STATE_IDLE;
volatile uint32_t sys_tick_ms      = 0;

/* Set when the master writes to a register that requires the main loop to act
 * (config or LED brightness). The main loop clears it after applying, so I2C
 * writes keep latency bounded and ISRs never call Charlie_* functions. */
static volatile bool regs_dirty = false;

/* Set by the I2C ISR when the master writes a non-zero value to the command
 * register (0x00). The reset itself runs in the main loop so the current I2C
 * transaction finishes (STOP seen by the master) before the MCU resets. */
static volatile bool reset_pending = false;

/* Prototypes */
static void APP_SystemClockConfig(void);
static void APP_GPIOConfig(void);
static void APP_I2C_Slave_Init(void);
static void APP_Encoder_Init(void);
static void APP_Charlie_Timer_Init(void);
static void APP_IWDG_Init(void);
static void APP_ApplyConfig(void);
static void APP_ApplyLedRegisters(void);

int main(void) {
    APP_SystemClockConfig();

    /* Latch the reset cause of the boot we are running now, then clear the
     * flags in RCC_CSR so register 0x02 reports the most recent reset only
     * (the flags accumulate across resets otherwise). */
    uint8_t reset_cause = 0;
    if (LL_RCC_IsActiveFlag_PWRRST())
        reset_cause |= RESET_CAUSE_POR;
    if (LL_RCC_IsActiveFlag_PINRST())
        reset_cause |= RESET_CAUSE_PIN;
    if (LL_RCC_IsActiveFlag_SFTRST())
        reset_cause |= RESET_CAUSE_SOFT;
    if (LL_RCC_IsActiveFlag_IWDGRST())
        reset_cause |= RESET_CAUSE_IWDG;
#ifdef WWDG
    if (LL_RCC_IsActiveFlag_WWDGRST())
        reset_cause |= RESET_CAUSE_WWDG;
#endif
    if (LL_RCC_IsActiveFlag_OBLRST())
        reset_cause |= RESET_CAUSE_OBL;
    LL_RCC_ClearResetFlags();

    APP_GPIOConfig();
    APP_I2C_Slave_Init();
    APP_Encoder_Init();

    Charlie_Init();
    APP_Charlie_Timer_Init();
    Animations_Init();

    // Initialize memory
    for (int i = 0; i < REG_COUNT; i++) {
        if (i >= REG_GP_BASE)
            device_memory[i] = REG_GP_DEFAULT;
        else
            device_memory[i] = 0x00;
    }

    /* Firmware version, big-endian */
    device_memory[REG_FW_VERSION_HI] = (uint8_t)(FW_VERSION >> 8);
    device_memory[REG_FW_VERSION_LO] = (uint8_t)(FW_VERSION & 0xFF);

    /* Push state default: not pushed (bit 0 clear) */
    device_memory[REG_ENC_PUSH_STATE] = 0x00;

    /* Cause of the reset that started this boot, for the host to read */
    device_memory[REG_RESET_CAUSE] = reset_cause;

    /* Active animation and its timing setting, exposed in registers 0x0E-0x0F */
    device_memory[REG_ANIMATION]          = Animations_Get();
    device_memory[REG_ANIMATION_SETTINGS] = Animations_GetSettings();

    /* Apply config-dependent display settings once at boot */
    APP_ApplyConfig();
    APP_ApplyLedRegisters();

    APP_IWDG_Init();

    while (1) {
        if (reset_pending) {
            NVIC_SystemReset(); // does not return
        }
        if (regs_dirty) {
            regs_dirty = false;
            APP_ApplyConfig();
            APP_ApplyLedRegisters();
        }
        // Charlie_Tick() now runs from the TIM16 update ISR at a fixed cadence;
        // sleep until any interrupt wakes us instead of spinning on the loop.
        Animations_Tick();

        /* The loop wakes at least once per animation tick (ANIMATION_TICK_MS,
         * driven by the TIM16 ISR); kick the watchdog here so a stalled main
         * loop (or a lost tick interrupt) recovers via an IWDG reset instead
         * of hanging silently. */
        LL_IWDG_ReloadCounter(IWDG);

        __WFI();
    }
}

void APP_MarkRegsDirty(void) {
    regs_dirty = true;
}

void APP_ResetRequest(void) {
    reset_pending = true;
}

static void APP_ApplyConfig(void) {
    Charlie_GammaEnable(!(device_memory[REG_CONFIG] & CFG_LED_LINEAR));
}

/* Push the LED brightness registers (0x10-0x1B) into the charlieplex driver.
 * Charlie_SetLED() clamps out-of-range values to full on. */
static void APP_ApplyLedRegisters(void) {
    for (uint8_t i = 0; i < REG_LED_COUNT; i++) {
        Charlie_SetLED(i, device_memory[REG_LED_BASE + i]);
    }
}

static void APP_SystemClockConfig(void) {
    LL_RCC_HSI_Enable();
    while (LL_RCC_HSI_IsReady() != 1)
        ;
    LL_RCC_SetAHBPrescaler(LL_RCC_SYSCLK_DIV_1);
    LL_RCC_SetSysClkSource(LL_RCC_SYS_CLKSOURCE_HSISYS);
    while (LL_RCC_GetSysClkSource() != LL_RCC_SYS_CLKSOURCE_STATUS_HSISYS)
        ;
    LL_RCC_SetAPB1Prescaler(LL_RCC_APB1_DIV_1);
    LL_Init1msTick(8000000);
    SysTick->CTRL |= SysTick_CTRL_TICKINT_Msk;
    LL_SetSystemCoreClock(8000000);
}

static void APP_GPIOConfig(void) {
    LL_IOP_GRP1_EnableClock(LL_IOP_GRP1_PERIPH_GPIOB);
    LL_GPIO_InitTypeDef GPIO_InitStruct = {0};

    // PB5 active low LED
    GPIO_InitStruct.Pin        = LL_GPIO_PIN_5;
    GPIO_InitStruct.Mode       = LL_GPIO_MODE_OUTPUT;
    GPIO_InitStruct.Speed      = LL_GPIO_SPEED_FREQ_LOW;
    GPIO_InitStruct.OutputType = LL_GPIO_OUTPUT_PUSHPULL;
    GPIO_InitStruct.Pull       = LL_GPIO_PULL_NO;
    LL_GPIO_Init(GPIOB, &GPIO_InitStruct);

    // PB5 is active low: drive it high to keep the onboard LED off by default
    LL_GPIO_SetOutputPin(GPIOB, LL_GPIO_PIN_5);
}

static void APP_I2C_Slave_Init(void) {
    /* Enable GPIOA peripheral clock */
    LL_IOP_GRP1_EnableClock(LL_IOP_GRP1_PERIPH_GPIOA);

    /* Enable I2C1 peripheral clock */
    LL_APB1_GRP1_EnableClock(LL_APB1_GRP1_PERIPH_I2C1);

    /* Configure SCL pin: Alternative function, High speed, Open-drain, Pull-up */
    LL_GPIO_InitTypeDef GPIO_InitStruct = {0};

    GPIO_InitStruct.Pin                 = LL_GPIO_PIN_3;
    GPIO_InitStruct.Mode                = LL_GPIO_MODE_ALTERNATE;
    GPIO_InitStruct.Speed               = LL_GPIO_SPEED_FREQ_HIGH;
    GPIO_InitStruct.OutputType          = LL_GPIO_OUTPUT_OPENDRAIN;
    GPIO_InitStruct.Pull                = LL_GPIO_PULL_UP;
    GPIO_InitStruct.Alternate           = LL_GPIO_AF_12;
    LL_GPIO_Init(GPIOA, &GPIO_InitStruct);

    /* Configure SDA pin: Alternative function, High speed, Open-drain, Pull-up */
    GPIO_InitStruct.Pin        = LL_GPIO_PIN_2;
    GPIO_InitStruct.Mode       = LL_GPIO_MODE_ALTERNATE;
    GPIO_InitStruct.Speed      = LL_GPIO_SPEED_FREQ_HIGH;
    GPIO_InitStruct.OutputType = LL_GPIO_OUTPUT_OPENDRAIN;
    GPIO_InitStruct.Pull       = LL_GPIO_PULL_UP;
    GPIO_InitStruct.Alternate  = LL_GPIO_AF_12;
    LL_GPIO_Init(GPIOA, &GPIO_InitStruct);

    /* Reset I2C */
    LL_APB1_GRP1_ForceReset(LL_APB1_GRP1_PERIPH_I2C1);
    LL_APB1_GRP1_ReleaseReset(LL_APB1_GRP1_PERIPH_I2C1);

    /* Enable NVIC interrupt */
    NVIC_SetPriority(I2C1_IRQn, 0);
    NVIC_EnableIRQ(I2C1_IRQn);

    /* I2C Initialisation */
    LL_I2C_InitTypeDef I2C_InitStruct = {0};
    I2C_InitStruct.ClockSpeed         = I2C_SPEEDCLOCK;
    I2C_InitStruct.DutyCycle          = LL_I2C_DUTYCYCLE_16_9;
    I2C_InitStruct.OwnAddress1        = SLAVE_ADDRESS;
    I2C_InitStruct.TypeAcknowledge    = LL_I2C_ACK; // Always ACK
    LL_I2C_Init(I2C1, &I2C_InitStruct);

    // Enable all necessary interrupts for a Register-based Slave
    LL_I2C_EnableIT_EVT(I2C1);
    LL_I2C_EnableIT_BUF(I2C1);
    LL_I2C_EnableIT_ERR(I2C1);

    LL_I2C_Enable(I2C1);
}

static void APP_Encoder_Init(void) {
    // GPIOA clock already enabled by I2C init
    LL_GPIO_InitTypeDef GPIO_InitStruct = {0};

    // EncA (PA5), EncB (PA4), EncSW (PA0) — input with pull-up
    GPIO_InitStruct.Pin  = LL_GPIO_PIN_5 | LL_GPIO_PIN_4 | LL_GPIO_PIN_0;
    GPIO_InitStruct.Mode = LL_GPIO_MODE_INPUT;
    GPIO_InitStruct.Pull = LL_GPIO_PULL_UP;
    LL_GPIO_Init(GPIOA, &GPIO_InitStruct);

    // Configure EXTI for EncA to detect rotation; direction is read from
    // EncB's level at the moment EncA transitions.
    // ENCODER_TRIGGER_TOGGLE counts both edges (one tick per detent on encoders
    // that produce one EncA edge per detent); the default falling-edge-only mode
    // gives one tick per two detents on such encoders. The ENC_A_* macros follow
    // ENCODER_AB_SWAP, so the trigger moves with the swapped phase.
    LL_EXTI_InitTypeDef EXTI_InitStruct = {0};
    EXTI_InitStruct.Line                = ENC_A_EXTI_LINE;
    EXTI_InitStruct.LineCommand         = ENABLE;
    EXTI_InitStruct.Mode                = LL_EXTI_MODE_IT;
#ifdef ENCODER_TRIGGER_TOGGLE
    EXTI_InitStruct.Trigger = LL_EXTI_TRIGGER_RISING_FALLING;
#else
    EXTI_InitStruct.Trigger = LL_EXTI_TRIGGER_FALLING;
#endif
    LL_EXTI_Init(&EXTI_InitStruct);

    // Configure EXTI for PA0 (EncSW) — trigger on both edges to detect press/release
    EXTI_InitStruct.Line    = LL_EXTI_LINE_0;
    EXTI_InitStruct.Trigger = LL_EXTI_TRIGGER_RISING_FALLING;
    LL_EXTI_Init(&EXTI_InitStruct);

    // Connect EXTI lines to GPIOA
    LL_EXTI_SetEXTISource(LL_EXTI_CONFIG_PORTA, ENC_A_EXTI_SOURCE);
    LL_EXTI_SetEXTISource(LL_EXTI_CONFIG_PORTA, LL_EXTI_CONFIG_LINE0);

    // Line 0 is serviced by EXTI0_1_IRQHandler, line 5 by EXTI4_15_IRQHandler —
    // both vectors need enabling, not just one, since EncSW and EncA now sit
    // on different NVIC lines.
    NVIC_SetPriority(EXTI0_1_IRQn, 1); // lower priority than I2C
    NVIC_EnableIRQ(EXTI0_1_IRQn);
    NVIC_SetPriority(EXTI4_15_IRQn, 1); // lower priority than I2C
    NVIC_EnableIRQ(EXTI4_15_IRQn);
}

/* Charlieplex refresh timer. The main loop used to spin-call Charlie_Tick()
 * unconditionally, which pinned the CPU at 100% and tied PWM timing to loop
 * iteration count. TIM16 now fires a periodic update interrupt that advances
 * Charlie_Tick() at a fixed cadence; the main loop sleeps with __WFI between
 * ticks. With the 8 MHz HSI prescaled to a 1 MHz counting clock and a 24 us
 * period, one full PWM cycle (12 LEDs * 64 steps = 768 sub-frames) takes
 * ~18.4 ms ~ 54 Hz, flicker-free. */
#define CHARLIE_TICK_US 24

static void APP_Charlie_Timer_Init(void) {
    LL_APB1_GRP2_EnableClock(LL_APB1_GRP2_PERIPH_TIM16);

    LL_TIM_SetPrescaler(TIM16, __LL_TIM_CALC_PSC(SystemCoreClock, 1000000));
    LL_TIM_SetAutoReload(TIM16, CHARLIE_TICK_US - 1);
    LL_TIM_SetCounterMode(TIM16, LL_TIM_COUNTERMODE_UP);
    LL_TIM_EnableARRPreload(TIM16);
    LL_TIM_EnableUpdateEvent(TIM16);
    LL_TIM_ClearFlag_UPDATE(TIM16);
    LL_TIM_EnableIT_UPDATE(TIM16);

    NVIC_SetPriority(TIM16_IRQn, 2); // lowest priority: I2C > EXTI > refresh
    NVIC_EnableIRQ(TIM16_IRQn);

    LL_TIM_EnableCounter(TIM16);
}

/* Independent watchdog, clocked from the LSI so it keeps running even if the
 * HSI/system clock dies. Once enabled it can only be stopped by a reset,
 * so the main loop kicks it every iteration (see the while(1) in main()).
 * With a /32 prescaler the ~32 kHz LSI gives a ~1 ms tick, so the timeout
 * in ms equals the reload value + 1. The IWDG registers sit on the APB1
 * bus but are powered independently; writing them only needs the write
 * access key, no bus clock enable. */
static void APP_IWDG_Init(void) {
    LL_RCC_LSI_Enable();
    while (LL_RCC_LSI_IsReady() != 1)
        ;

    /* While the core is halted under a debugger, freeze the watchdog so
     * breakpoints don't trip a reset; DBGMCU needs its APB1 clock enabled. */
    LL_APB1_GRP1_EnableClock(LL_APB1_GRP1_PERIPH_DBGMCU);
    LL_DBGMCU_APB1_GRP1_FreezePeriph(LL_DBGMCU_APB1_GRP1_IWDG_STOP);

    LL_IWDG_EnableWriteAccess(IWDG);
    LL_IWDG_SetPrescaler(IWDG, LL_IWDG_PRESCALER_32);
    LL_IWDG_SetReloadCounter(IWDG, IWDG_TIMEOUT_MS - 1);
    /* Wait for the prescaler and reload writes to be acknowledged before
     * starting the counter, so the first period is the configured one. */
    while (LL_IWDG_IsActiveFlag_PVU(IWDG) || LL_IWDG_IsActiveFlag_RVU(IWDG))
        ;
    LL_IWDG_ReloadCounter(IWDG);
    LL_IWDG_Enable(IWDG);
}

void APP_ErrorHandler(void) {
    // No kick here on purpose: the IWDG reset is the way out of a trap.
    while (1)
        ;
}

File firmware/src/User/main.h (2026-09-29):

/**
 ******************************************************************************
 * @file    main.h
 * @author  MCU Application Team
 * @brief   Header for main.c file.
 *          This file contains the common defines of the application.
 ******************************************************************************
 * @attention
 *
 * <h2><center>&copy; Copyright (c) 2023 Puya Semiconductor Co.
 * All rights reserved.</center></h2>
 *
 * This software component is licensed by Puya under BSD 3-Clause license,
 * the "License"; You may not use this file except in compliance with the
 * License. You may obtain a copy of the License at:
 *                        opensource.org/licenses/BSD-3-Clause
 *
 ******************************************************************************
 * @attention
 *
 * <h2><center>&copy; Copyright (c) 2016 STMicroelectronics.
 * All rights reserved.</center></h2>
 *
 * This software component is licensed by ST under BSD 3-Clause license,
 * the "License"; You may not use this file except in compliance with the
 * License. You may obtain a copy of the License at:
 *                        opensource.org/licenses/BSD-3-Clause
 *
 ******************************************************************************
 */

/* Define to prevent recursive inclusion -------------------------------------*/
#ifndef __MAIN_H
#define __MAIN_H

#ifdef __cplusplus
extern "C" {
#endif

/* Includes ------------------------------------------------------------------*/
#include "charlieplex.h"
#include "py32f0xx_it.h"
#include "py32f0xx_ll_bus.h"
#include "py32f0xx_ll_cortex.h"
#include "py32f0xx_ll_exti.h"
#include "py32f0xx_ll_gpio.h"
#include "py32f0xx_ll_i2c.h"
#include "py32f0xx_ll_iwdg.h"
#include "py32f0xx_ll_pwr.h"
#include "py32f0xx_ll_rcc.h"
#include "py32f0xx_ll_system.h"
#include "py32f0xx_ll_tim.h"
#include "py32f0xx_ll_utils.h"
#include <stdbool.h>

#if defined(USE_FULL_ASSERT)
#include "py32_assert.h"
#endif /* USE_FULL_ASSERT */

/* Private includes ----------------------------------------------------------*/
/* Exported types ------------------------------------------------------------*/
/* Exported constants --------------------------------------------------------*/

/* Firmware version, exposed big-endian in registers 0x00-0x01.
 * Set through FW_VERSION in the Makefile (passed as a -D flag); the fallback
 * matches the Makefile defaults and keeps IDE builds working. */
#ifndef FW_VERSION
#define FW_VERSION 0x0100u
#endif
#define HW_VERSION 0x0100u // hardware version, used for peripheral mapping and other hardware-specific behavior

/* I2C slave address (7-bit) */
#define I2C_SLAVE_ADDR 0x36

/* Register map */
#define REG_COUNT 256               /* 0x00-0xFF, one byte each */
#define REG_FW_VERSION_HI 0x00      /* R/O: firmware version, high byte */
#define REG_SOFT_RESET 0x00         /* W: command register (same address as version hi): \
                                        writing any non-zero value soft-resets the MCU */
#define REG_FW_VERSION_LO 0x01      /* R/O: firmware version, low byte */
#define REG_RESET_CAUSE 0x02        /* R/O: reset cause of the last boot, see RESET_CAUSE_* bits */
#define REG_CONFIG 0x03             /* R/W: configuration bits, default 0x00 */
#define REG_ENC_COUNT_HI 0x04       /* R/W: encoder rotation count, high byte */
#define REG_ENC_COUNT_LO 0x05       /* R/W: encoder rotation count, low byte */
#define REG_ENC_PUSH_COUNT 0x06     /* R/W: encoder push button count */
#define REG_ENC_PUSH_STATE 0x07     /* R/O: encoder push button state */
#define REG_ANIMATION 0x0E          /* R/W: active animation, see animations.h:   \
                                      0x00 = IDLE (custom control over the LEDs), \
                                      0x01 = LOADING, 0x02 = FLASHING, ... */
#define REG_ANIMATION_SETTINGS 0x0F /* R/W: timing setting of the animation         \
                                  selected through REG_ANIMATION, see animations.h. \
                                  Writing REG_ANIMATION loads the new animation's   \
                                  default into this register. */
/* 0x08-0x0D: reserved, reads as 0x00, writes ignored */
#define REG_LED_BASE 0x10 /* R/W: LED brightness, one register per LED */
#define REG_LED_COUNT 12  /* 0x10-0x1B */
/* 0x1C-0x1F: reserved, reads as 0x00, writes ignored */
#define REG_GP_BASE 0x20 /* R/W: general-purpose I2C RAM */
#define REG_GP_DEFAULT 0x00
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

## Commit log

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2026-06-03 added draft KiCAD files
    [rack-ui-pcb.kicad_pcb, rack-ui-pcb.kicad_sch]
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2026-06-03 updated schematic & PCB
    [rack-ui-pcb.kicad_pcb, rack-ui-pcb.kicad_sch]
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2026-06-05 got I2C R/W working Now to implement the encoder handling
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2026-06-09 updated design wih new uC, added USB-C and UART chip
    [rack-ui-pcb.kicad_pcb, rack-ui-pcb.kicad_sch]
2026-06-11 added charlieplexed LED matrix
    [rack-ui-pcb.kicad_pcb, rack-ui-pcb.kicad_sch]
2026-06-11 routed TX/RX LEDs
    [rack-ui-pcb.kicad_pcb]
2026-06-15 updated white LED footprints
    [rack-ui-pcb.kicad_pcb, rack-ui-pcb.kicad_sch]
2026-06-16 updated footprints, part numbers
    [rack-ui-pcb.kicad_pcb, rack-ui-pcb.kicad_sch]
2026-09-16 updated pins to match PCB And other small fixes (volatile mismatches, missing prototypes,...)
    [charlieplex.h, main.c, py32f0xx_it.c]
2026-09-17 Optimise charlieplex hot path and tidy I2C read handler
    - Add Charlie_SetAllLEDs() bulk setter using memset; replace the 12-call
    Charlie_SetLED() loop in the 50ms tick with a single memset.
    - Cache the last applied GPIO state in charlie_apply_state() so repeated
    identical states (predominantly OFF at low brightness) skip the OTYPER/ODR
    register writes entirely.
    - Remove the dead '&& true' breakpoint guard in the I2C read handler.
    [charlieplex.c, charlieplex.h, main.c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]
2026-09-17 Fix PWM full-on, sample button once per I2C read, drive refresh from TIM16 + WFI
    #4 PWM top brightness: Charlie_SetLED now accepts 0..CHARLIE_PWM_STEPS
    (64 = full on) and the gamma LUT is scaled so the top of the ramp reaches
    100% duty instead of capping at 63/64.
    #5 I2C read handler: move the button-level GPIO read out of the per-byte TXE
    path into the ADDR-match branch so it runs once per read transaction.
    #8 Fix stale charlieplex.c doc comment (max accepted brightness).
    #9 Charlieplex refresh now runs from a TIM16 update ISR at a fixed 24 us
    cadence (~54 Hz full-cycle); the main loop sleeps with __WFI between
    interrupts instead of spinning and tying PWM timing to loop itera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
    [charlieplex.c, charlieplex.h, main.c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]
2026-09-17 fixed out of bound count
    [main.c]
2026-09-17 moved gamma correction to charlieplexing source files
    [charlieplex.c, charlieplex.h, main.c]
2026-09-17 ci: fix ARM toolchain path and add newlib for nano.specs
    The apt package installs arm-none-eabi-gcc to /usr/bin, but ARM_TOOLCHAIN=/usr
    made the prefix /usr/arm-none-eabi- (missing /bin), causing 'No such file or
    directory'. Point ARM_TOOLCHAIN at /usr/bin. Also install libnewlib-arm-none-eabi
    since rules.mk links with -specs=nano.specs, and add a toolchain verify step.
2026-09-19 added gamma correction toggle for LED brightness, added value bound safeguards
    [charlieplex.c, charlieplex.h]
2026-09-19 docs: rewrite software/src README for the rack-ui firmware; ci: publish nightly build release
    - Document what the firmware actually does: encoder/button-to-I2C register
    map, charlieplexed LED driving with TIM16-driven PWM and gamma correction
    - Document the I2C address (0x36), full register map with access/default
    values, and i2c-tools examples
    - Add build/flash instructions (make targets, ARM_TOOLCHAIN, output files)
    - Add a nightly-release job to the firmware workflow that publishes the CI
    build outputs (app.bin/hex/elf) as a rolling prerelease tagged 'nightly'
2026-09-19 fix: include <stdbool.h> in charlieplex.h
    Charlie_GammaEnable(bool) was declared without <stdbool.h>; the build
    only worked while main.c transitively included it. Commit f2a77e1 removed
    that include path, breaking CI on main.
    [charlieplex.h]
2026-09-19 feat: new I2C register map with per-LED brightness, config bits and GP RAM
    - 0x00-0x01: firmware version (R/O, big-endian, default 0x0001)
    - 0x02: config register (reset-on-read toggles, encoder direction flip,
    push count direction, push state invert, gamma on/off)
    - 0x03-0x04: encoder rotation count (R/W, signed 16-bit big-endian,
    auto-clears after low byte is read unless disabled)
    - 0x05: push button count (R/W, auto-clears after read unless disabled)
    - 0x06: push button state (R/O, sampled live on transmit)
    - 0x10-0x1B: per-LED brightness (R/W, 0=off, 64=full, clamped)
    - 0x20-0xFF: general-purpose I2C RAM (R/W, default 0x42)
    - config/LED writes are applied by the main loop via a dirty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
    [main.c, main.h, py32f0xx_it.c]
2026-09-19 feat: config bit polarity per review - reset-on-read opt-in, GP RAM 0x00
    - Config bits 0/1 now: 1 = clear count after read, 0 (default) = keep.
    Reads no longer have hidden side effects unless the host opts in.
    - GP RAM (0x20-0xFF) default 0x00 instead of 0x42.
    - Gamma default unchanged (bit 5: 0 = gamma on, 1 = linear).
    - README and test.py updated to match.
    [main.h, py32f0xx_it.c]
2026-09-19 feat: soft reset via non-zero write to register 0x00
    Writing any non-zero value to 0x00 (the firmware version high byte) now
    requests a software reset. The I2C ISR only sets a flag; the main loop
    performs NVIC_SystemReset() so the current transaction completes and the
    master sees a clean STOP before the MCU restarts. Zero writes are ignored,
    and 0x00-0x01 still read as the firmware version.
    [main.c, main.h, py32f0xx_it.c]
2026-09-21 updated LCSC# field, added PCB text
    [rack-ui-pcb.kicad_pcb, rack-ui-pcb.kicad_sch]
2026-09-21 added v1.0 PCB files
    [rack-ui-v1.0_bom.csv, rack-ui-v1.0_designators.csv, rack-ui-v1.0_positions.csv]
2026-09-21 added v1.0 to production archive
    [rack-ui-pcb-v1.0.kicad_pcb, rack-ui-pcb-v1.0.kicad_sch]
2026-09-21 added hardware version definition and implement LED animation functions
2026-09-21 Refactor LED animations into animations.c/.h and add REG_ANIMATION (0x07)
    - Move all animation logic out of main.c into a dedicated animations module
    - Register 0x07 now selects the active animation:
    0x00 IDLE (custom LED control), 0x01 LOADING (default), 0x02 BREATHING
    - New animations only need an ID in Animation_Id_t plus one entry in the
    animation table
2026-09-21 Move REG_ANIMATION from 0x07 to 0x0F
    Keeps 0x07-0x0E free for future encoder settings registers.
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2026-09-21 Move register map docs to the firmware README and document the animation register
    - Revert the register map added to the root README; software/src/README.md
    already documents the I2C interface in detail
    - Document REG_ANIMATION (0x0F) there: register map row, dedicated section
    with the animation values, and i2c-tools examples
2026-09-21 Add ENCODER_TRIGGER_TOGGLE flag for rising+falling edge encoder counting
    Detented encoders that produce one EncA edge per detent (e.g. 36-detent
    parts) only showed 18 ticks per rotation with falling-edge-only EXTI
    triggering. Define ENCODER_TRIGGER_TOGGLE in main.h to trigger EXTI on
    both edges so each detent counts once; the IRQ handler needed no change
    since direction is decoded from EncB's level at the transition.
2026-09-21 Fix direction decode on rising edges in ENCODER_TRIGGER_TOGGLE mode
    The falling-edge-only decode (EncB high = increment) inverts on a rising
    EncA edge, so both-edge triggering made alternate ticks count in the
    wrong direction: slow rotation netted to zero (every edge passes the
    50 ms debounce) while fast rotation masked it (rising edges swallowed).
    Sample EncA's new level alongside EncB so the decode accounts for which
    edge fired, and halve the debounce window in toggle mode since events
    arrive twice as fast, keeping the same max rotation speed.
    [py32f0xx_it.c]
2026-09-21 Lower encoder debounce now that the RC hardware debounce is accounted for
    Each encoder line has a 100 nF cap to ground, so contact bounce is
    suppressed by the RC filter formed with the internal pull-ups. The
    25 ms software window was far too long for hand rotation speeds and
    dropped edges during fast spins in both-edge mode. Reduce it to a 2 ms
    glitch guard in toggle mode (5 ms falling-only, which sees half the
    edges at the same rotation speed).
    [py32f0xx_it.c]
2026-09-21 Reduce encoder glitch guard to 1 ms
    The RC filter (100 nF caps against the internal pull-ups) does the real
    debouncing; the software window only guards against spurious triggers
    and starts dropping legitimate edges above ~7 rev/s in both-edge mode.
    [py32f0xx_it.c]
2026-09-22 Add ENCODER_DIRECTION_FLIP compile-time direction default
    Define it in main.h to bake in reversed increment direction for a given
    encoder model (reversed phase wiring or mounting). It composes with the
    runtime CFG_ENC_DIR_FLIP config bit: the host can still flip direction
    over I2C, and both set cancel out.
    [main.h, py32f0xx_it.c]
2026-09-22 Add ENCODER_AB_SWAP flag and macro-driven encoder pin mapping
    Define ENCODER_AB_SWAP in main.h to swap the phase inputs for encoder
    models whose trigger output sits on the other phase: EncA moves to PA4
    (EXTI line 4), EncB to PA5. The pin/line assignment is now expressed as
    ENC_A_PIN / ENC_A_EXTI_LINE / ENC_A_EXTI_SOURCE / ENC_B_PIN macros so
    APP_Encoder_Init and the EXTI ISR follow the flag without duplicated
    ifdefs. Swapping the phases also inverts the decoded direction, so
    combine with ENCODER_DIRECTION_FLIP to keep the increment direction.
    [main.c, main.h, py32f0xx_it.c]
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2026-09-22 Fix LED ghosting in charlieplex driver: release pins before changing output type
    charlie_apply_state() wrote OTYPER before ODR. On any lit-to-lit
    transition the OTYPER write makes the new anode push-pull at its old
    (high) ODR level while the previous cathode is still driven low, so the
    LED bridging those two pins forward-biases for the window between the
    two writes. The window is also stretched whenever I2C/EXTI preempt the
    TIM16 refresh ISR inside it, and it repeats every scan, which made off
    LEDs visibly glow in the mixed-brightness animations (gauge, point,
    following) while staying masked in the uniform ones (loading,
    breathing).
    Release all charlieplex pins high with a single atomic BSR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
    [charlieplex.c]
2026-09-22 Mirror test suite results on the optional SSD1306 OLED
    Add a dependency-free SSD1306 driver module driven directly over the
    I2CDriver bus. The test suite now shows each step's title in the top 16
    pixel rows (the yellow band on two-color modules) with the step counter,
    live encoder readouts during interactive waits, and PASS/FAIL results.
    Runs console-only when no display is fitted.
    [test_suite.py]
2026-09-22 Fix SSD1306 showing stale or randomized content at startup
    The panel's GDDRAM is undefined at power-up, and the page-dirty flush
    skipped every page because the shadow copy starts as all zeros and
    matched the cleared framebuffer. Clear every page explicitly during
    init before turning the display on, so both a first run over random
    power-on RAM and a re-run over previous content start from blank.
2026-09-22 Move animation select to 0x0E, add animation settings register 0x0F
    Register 0x0E now selects the active animation and 0x0F holds its
    timing setting: LOADING and FLASHING step in tens of milliseconds
    (defaults 10 = 100 ms and 25 = 250 ms), PULSING in milliseconds
    (default 10 = 10 ms). Selecting an animation loads its default into
    0x0F, replacing the hard-coded per-animation tick constants.
    Update the firmware README and the interactive test suite to the new
    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
2026-09-22 Declare Animations_SetSettings in animations.h
    Fixes the implicit-declaration build error in py32f0xx_it.c.
    [animations.h]
2026-09-22 Fix all-on animation, add brightness settings for all-on/following/point
    - All-on/all-off no longer recurse back to IDLE from inside their start
    functions, which re-entered Animations_Set and hung the MCU before the
    LEDs were ever driven; they are now plain one-shot animations
    - All-on brightness now comes from the settings register 0x0F, whose
    default (full on) is loaded when the animation is selected, and a live
    write to 0x0F re-applies the new brightness immediately
    - FOLLOWING and POINT use 0x0F as the off-state brightness of the
    non-lit LEDs, default 0
    - Update the firmware README and test suite to the new semantics and
    the ALL_ON power-on default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
    [animations.c, animations.h, test_suite.py]
2026-09-22 Align README with ALL_ON default and settings register semantics
    Register 0x0F power-on default is 0x3F (ALL_ON full-on brightness),
    not the old PULSING 0x0A; the intro now mentions that the setting can
    be a speed or a brightness.
2026-09-22 Prepare for v1.0: move firmware to firmware/, version-driven app name, tag-based releases
    - Move software/src to firmware/src (history preserved via git mv)
    - Define the firmware version in the Makefile (FW_VERSION_MAJOR/MINOR,
    default 1.0); the code inherits it via -DFW_VERSION and the build
    products are named mu-cell_rack-ui_vX.Y (.bin/.elf/.hex/.lst)
    - Add 'make echo-version' so CI can query the version
    - CI: build from firmware/src; on vX.Y tags build with the tagged
    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
2026-09-23 added PCB step file
    [rack-ui-pcb.step]
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2026-09-23 updates PCB colors
    [rack-ui-pcb.kicad_pcb]
2026-09-24 Make gauge max range settable via 0x0F; dim non-gauge LEDs
    - The animation settings register (0x0F) now holds the gauge maximum value
    (default 100): the encoder count is scaled and clamped against it, so
    ranges like 0-10 or 0-250 can be selected at runtime.
    - New ANIMATION_GAUGE_DIM_UNUSED_LEDS build flag holds the three LEDs
    outside the gauge arc at a low brightness (ANIMATION_GAUGE_UNUSED_BRIGHTNESS)
    while the gauge animation is active, instead of keeping their previous state.
    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
2026-09-24 Document build flags in README; add gauge range test to test suite
    - New 'Build flags and tunable constants' section in firmware/src/README.md
    covering every optional #define flag (encoder, gauge dimming, USE_FULL_ASSERT)
    and the tunable constants with their defaults and owning headers.
    - test_suite.py: new 'Gauge maximum range (0x0F)' step that writes encoder
    counts above/below/inside the range and verifies the clamping and the LED
    bar levels against the firmware's animations.h gauge layout, for the
    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
2026-09-24 Move gauge range checks into the All animations GAUGE phase
    The 0x0F maximum is now exercised while the GAUGE animation is selected in
    the animation cycle: default range (0-100), then 0-10, then 0-255, each
    checked for count clamping and LED bar levels against the firmware header
    layout. Drops the separate dedicated step.
2026-09-26 Add IWDG watchdog; expose reset cause in register 0x07
    - Enable the independent watchdog at boot (LSI clock, /32 prescaler,
    IWDG_TIMEOUT_MS = 500 ms) and kick it from the main loop, so a hung
    firmware resets the MCU instead of freezing the panel.
    - Freeze the IWDG while the core is halted under a debugger (DBGMCU stop).
    - Latch the RCC_CSR reset flags at boot into new read-only register 0x07
    (POR/PIN/SOFT/IWDG/WWDG/OBL bits), then clear them so the register
    reports the most recent reset only.
    - Test suite: verify register 0x07 is read-only and that it reports the
    soft reset (with no IWDG or stale POR bits) after a reset via 0x00.
    - Bump firmware version to 1.1.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
    [main.c, main.h, test_suite.py]
2026-09-26 Move reset cause to 0x02, shifting config/encoder registers up; v1.0
    - Reset cause now lives at 0x02; config moves to 0x03, rotation count to
    0x04-0x05, push count to 0x06 and push state to 0x07.
    - Revert the firmware version to 1.0 (not released yet).
    - Update the register map table, config-register notes, i2c-tools
    examples and both host test scripts to the new addresses.
    [main.c, main.h, py32f0xx_it.c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]
2026-09-28 Fix centered gauge animation, document it and add test coverage
    - fix the GAUGE_CENTER LED mapping to use the gauge arc
    (ANIMATION_GAUGE_START_LED offset, center LED always on)
    - fix the operator-precedence error in the per-LED value ranges
    - compute partial brightness from the absolute value so negative
    counts mirror positive ones
    - widen the value type to int so counts above 127 do not overflow
    - write both sides every step so the inactive side turns off when
    the count flips sign
    - document GAUGE_CENTER (0x83) in firmware/src/README.md
    - add GAUGE_CENTER to the hardware test suite with range, clamping
    and LED level checks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
    [animations.c, animations.h, test_suite.py]
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2026-09-29 Write both encoder count bytes in one I2C transaction in the gauge tests

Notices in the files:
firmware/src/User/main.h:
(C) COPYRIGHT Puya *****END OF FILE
